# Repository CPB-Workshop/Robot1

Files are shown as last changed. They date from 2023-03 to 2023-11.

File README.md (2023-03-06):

# Robot1

## Code

Dans le dossier Code vous trouverez les différents codes pour tester les composants uns à uns de votre machine puis dans final en fonction du choix fait, une version "final" du code permettant de piloter completement la machine.

Tous les comportements "auto" n'ont pas été implémentés de sorte d'avoir un controle total de la machine, cependant les parechocs emettrons bien un signal et les photorésistances demandes normalement un étalonage pour chaques machines de sorte à ne pas envoyer un signal faux positif qui correspond a la lumière ambiante. Une routine est en cours de création pour automatiser cette dernière)

## Fritzing

Dans le dossier Fritzing vous trouverez le schéma de la machine en document Fritzing. le logiciel est distribué gratuitement et légalement sous une base de version précédente sur le site de l'éditeur ici : https://fritzing.org/releases/0-9-3b. Une version est ici jointe dans le zip pour exploiter le fichier et y découvrir le cablage de la machine.
ATTENTION le fichier CodeFull.ino (code arduino) n'est pas remplis, il correspond a ce que fritzing met a dispo avec le projet. Pour le bon code, voir la section précédente.

## WHAT'S NEXT

En cas de besoin/souhait d'évolution, n'hésitez pas à me contacter où à laisser une issue sur le projet.

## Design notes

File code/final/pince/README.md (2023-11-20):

# Code Final - Option Pince

Code final du mod "Pince" proposant de prendre le controlle complet de la machine via une application sur smartphone

## Flasher le robot

### 0. Installer le logiciel Arduino
Pour flasher le code, vous devrez installer arduino (https://downloads.arduino.cc/arduino-1.8.19-windows.exe)

### 1. Branchez l'arduino par USB
Vous devez débrancher le bluetooth (module bleu), prenez bien note de la manière dont tout est branché avant (prenez un photo, cela ne sera probablement pas de trop)

Si la pile est branché, débranchez la.

Branchez ensuite le cable USB sur le port de l'arduino et au PC, on est parré !

### 2. Récuperer le code

Une fois fait, téléchargez le code par ici (https://github.com/CPB-Workshop/Robot1/archive/refs/heads/main.zip)

Dezippez le et allez dans le dossier code / final / pince et double cliquez sur pince.ino

### 3. Réglage avant de flasher

Dans la section "outils", vous devez choisir :
* Type de carte : "Arduino Nano"
* Processeur: ou bien "ATMega328P" ou bien  "ATMega328P (Old bootloader)" cela dépend du microOS dans l'arduino, pas distinguible physiquement, a changer sur lors du flash cela ne marche pas
* Port: "ComX" X étant variable d'un pc a l'autre, d'un Port USB a l'autre. Normalement si vous avez branché avant d'ouvrir l'onglet vous devriez en voir au moins un. Si plus d'un, tentez de débrancher et rouvrir l'onglet pour voir lequel aurais disparus et qui serait donc votre Arduino

Cela donne en somme ceci a la fin (Old bootload ou port Com près)

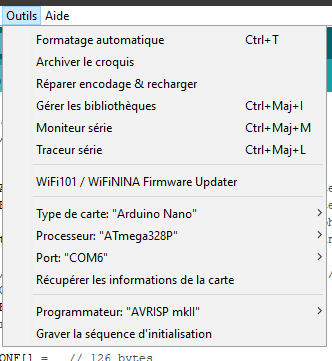
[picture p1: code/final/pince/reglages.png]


### 4. Flashez !

Utilisez la flèche pour verrifier le contenu du code, si aucune erreur n'apparait en rouge en dessous, utilisez la fleche pour transferrer le code

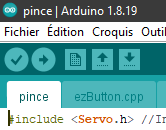
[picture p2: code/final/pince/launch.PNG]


### 5. Rebranchez...

Débranchez l'USB, rebranchez le bluetooth, rebranchez la batterie, on est partis !

### 6. L'app mobile

Pour le controller par bluetooth via votre smartphone android, il faut télécharger l'application RemoteXY

### AppStore
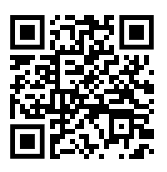
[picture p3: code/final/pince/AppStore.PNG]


### G-Play
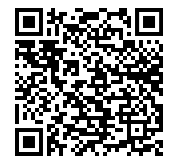
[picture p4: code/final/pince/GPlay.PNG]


et ajouter une nouvel appareil : le + en haut a droite 
puis bluetooth classic et vous devriez voir un appareil comme HC-05 ou HC-06 ou le nom que vous aurez choisis pour votre Robot.

Dès lors le robot est connecté et vous pouvez découvrir l'interface de controle pour expérimenter le code et vos modifs. Happy coding ;)

# TROUBLESHOOTING

## Robot qui avance pas droit ou recule
En cas de probleme de sens des moteurs (le robot tourne au lieux de rouler droit/recule) ont peut modifier le code a loisir sur la partie suivante :

```C++
    void lancerRotationMoteurPontA(bool marcheAvant, char vitesse) {
        digitalWrite(borneIN2, marcheAvant ? LOW : HIGH);    // inversion LOW et HIGH, Idem en dessous pour inverser le comportement d'une roue            
        digitalWrite(borneIN1, marcheAvant ? HIGH : LOW);
        
        analogWrite(borneENA, vitesse);       // Active l'alimentation du moteur 1
    }
    //[...]
    void lancerRotationMoteurPontB(bool marcheAvant, char vitesse) {
        digitalWrite(borneIN3, marcheAvant ? LOW : HIGH);    // inversion LOW et HIGH, Idem en dessous pour inverser le comportement d'une roue            
        digitalWrite(borneIN4, marcheAvant ? HIGH : LOW);
        
        analogWrite(borneENB, vitesse);       // Active l'alimentation du moteur 2
    }
```

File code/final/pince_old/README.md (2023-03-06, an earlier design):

# Code Final - Option Pince

Si vous avez décidé de passer par le code final, il faut alors flasher l'arduino (toujours bluetooth débranché) avec le code fournis (pince.ino)

Pour le controller par bluetooth via votre smartphone android, il faut télécharger l'application Bluetooth Electronics de Keuwlsoft

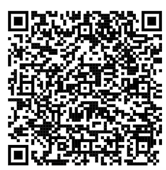
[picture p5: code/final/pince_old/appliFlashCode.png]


Ensuite importer le fichier "CPBRobotPince.kwl" pour obtenir un dashboard qui va permettre de commander la machine (ne pas oublier de rebrancher le bluetooth ;) )

# TROUBLESHOOTING

## Robot qui avant pas droit ou recule
En cas de probleme de sens des moteurs (le robot tourne au lieux de rouler droit/recule) ont peut modifier le code a loisir sur la partie suivante :

```C++
    void lancerRotationMoteurPontA(bool marcheAvant, char vitesse) {
        digitalWrite(borneIN2, marcheAvant ? LOW : HIGH);    // inversion LOW et HIGH, Idem en dessous pour inverser le comportement d'une roue            
        digitalWrite(borneIN1, marcheAvant ? HIGH : LOW);
        
        analogWrite(borneENA, vitesse);       // Active l'alimentation du moteur 1
    }
    //[...]
    void lancerRotationMoteurPontB(bool marcheAvant, char vitesse) {
        digitalWrite(borneIN3, marcheAvant ? LOW : HIGH);    // inversion LOW et HIGH, Idem en dessous pour inverser le comportement d'une roue            
        digitalWrite(borneIN4, marcheAvant ? HIGH : LOW);
        
        analogWrite(borneENB, vitesse);       // Active l'alimentation du moteur 2
    }
```

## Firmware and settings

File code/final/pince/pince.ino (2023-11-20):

#include <Servo.h> //Inclu avec arduino
#include "ezButton.h"
#include "RemoteXY/RemoteXY.h"

//REGLAGES
#define vitesseMinA 200 //à tester, a augmenter 1 par 1 si le moteur tourne pas a la même vitesse que l'autre quand ca doit aller droit (diff physique)
#define vitesseMinB 170 //à tester, a augmenter 1 par 1 si le moteur tourne pas a la même vitesse que l'autre quand ca doit aller droit (diff physique)
#define pinceFerme 0 //normalement est calibré au montage (diff physique) peux pas être négatif
#define pinceOuverte 140 //à tester, a augmenter 1 par 1 si la pince s'ouvre pas totalement (diff physique)

////////////////////////////////////////////////////////////////////////////////////////
//ACTIVATION CONTROLLE BLUETOOTH SUR LA SERIAL HARD (0-1)
#define REMOTEXY_SERIAL_SPEED 9600
//RemoteXY configurate  
#pragma pack(push, 1)
uint8_t RemoteXY_CONF[] =   // 126 bytes
  { 255,4,0,16,0,148,0,16,27,2,5,33,66,30,30,30,29,63,30,30,
  2,26,31,2,0,36,39,22,11,31,7,22,11,2,26,31,31,65,117,116,
  111,0,77,97,110,117,101,108,0,68,51,9,4,58,26,5,26,53,31,8,
  36,135,94,71,97,117,99,104,101,0,68,114,111,105,116,101,0,67,101,110,
  116,114,101,0,1,0,10,39,18,18,4,68,21,21,2,31,80,105,110,99,
  101,0,72,100,70,4,27,27,4,4,24,24,2,26,121,37,0,0,0,0,
  0,0,250,68,0,0,0,0,1,0,0,0,0,0,0,200,66,4,0,0,
  200,66,0,0,122,68,95,0,0,122,68,0,0,250,68 };
// this structure defines all the variables and events of your control interface 
struct {
  int8_t joystick_1_x; // from -100 to 100  
  int8_t joystick_1_y; // from -100 to 100  
  uint8_t switch_1; // =1 if switch ON and =0 if OFF 
  uint8_t button_1; // =1 if button pressed, else =0 
    // output variables
  float onlineGraph_1_var1;
  float onlineGraph_1_var2;
  float onlineGraph_1_var3;
  float circularbar_1;  // from 0 to 2000 
    // other variable
  uint8_t connect_flag;  // =1 if wire connected, else =0 
} RemoteXY;
#pragma pack(pop)
//////////////////////////////////////////////////////////////////////////////////////////

//CABLAGE MOTEUR
#define borneENA        6       // On associe la borne "ENA" du L298N à la pin D8 de l'arduino
#define borneIN1        7       // On associe la borne "IN1" du L298N à la pin D7 de l'arduino
#define borneIN2        8       // On associe la borne "IN2" du L298N à la pin D6 de l'arduino
#define borneIN3        5       // On associe la borne "IN3" du L298N à la pin D5 de l'arduino
#define borneIN4        4       // On associe la borne "IN4" du L298N à la pin D4 de l'arduino
#define borneENB        3       // On associe la borne "ENB" du L298N à la pin D3 de l'arduino

//CABLAGE SONAR
#define TRIGGER_PIN 11 // Broche TRIGGER
#define ECHO_PIN 12    // Broche ECHO

// SERVO
#define servoPin 10

// PARECHOC
#define SWITCHG 9 // Broche Gauche (a échanger en dessous si pas bon)
#define SWITCHD 2 // Broche Droite (a échanger au dessus si pas bon)

//PHOTORESISTANCES
#define RD A0  // composante photoresistor sur la pin A0
#define RC A1  // composante photoresistor sur la pin A1
#define RG A2  // composante photoresistor sur la pin A2

//CONSTANTES
/* Constantes pour le timeout */
const unsigned long MEASURE_TIMEOUT = 25000UL; // 25ms = ~8m à 340m/s
/* Vitesse du son dans l'air en mm/us */
const float SOUND_SPEED = 340.0 / 1000;

//STOCKAGE
String msg;
// Creation de l'objet servo
Servo myservo;
//Creation des objets parechoc
ezButton limitSwitchG(SWITCHG);  // create ezButton object;
ezButton limitSwitchD(SWITCHD);  // create ezButton object;
CRemoteXY *remotexy; //interface bluetooth

void setup() {
  
  // Configuration de toutes les pins de l'Arduino en "sortie" (car elles attaquent les entrées du module L298N)
  pinMode(borneENA, OUTPUT);
  pinMode(borneIN1, OUTPUT);
  pinMode(borneIN2, OUTPUT);
  pinMode(borneIN3, OUTPUT);
  pinMode(borneIN4, OUTPUT);
  pinMode(borneENB, OUTPUT);

  //SONAR
  pinMode(TRIGGER_PIN, OUTPUT);
  digitalWrite(TRIGGER_PIN, LOW); // La broche TRIGGER doit être à LOW au repos
  pinMode(ECHO_PIN, INPUT);

  //SERVO
  // appel de la fonction attach de l'objet
  myservo.attach(servoPin);
  //par defaut on ouvre
  myservo.write(pinceOuverte);

  //PARECHOC
  limitSwitchG.setDebounceTime(50); // set debounce time to 50 milliseconds
  limitSwitchD.setDebounceTime(50); // set debounce time to 50 milliseconds

  //PHOTORESISTANCES
  pinMode(RD, INPUT);
  pinMode(RC, INPUT);
  pinMode(RG, INPUT);


  //init bluetooth interface
  remotexy = new CRemoteXY (
    RemoteXY_CONF_PROGMEM, 
    &RemoteXY, 
    "", 
    new CRemoteXYStream_HardSerial (
      &Serial,       
      REMOTEXY_SERIAL_SPEED     // REMOTEXY_SERIAL_SPEED
    )
  ); 
}


void loop() {
  //d'abord on fait nos mesure
  float distanceMM = mesureSonar();
  RemoteXY.circularbar_1 = distanceMM;
  RemoteXY.onlineGraph_1_var1 = analogRead(RG);
  RemoteXY.onlineGraph_1_var2 = analogRead(RD);
  RemoteXY.onlineGraph_1_var3 = analogRead(RC);
  //readSerialPort();
  checkParechoc(RemoteXY.switch_1);
  //TODO lux sensor
  //ensuite on rafraichis l'interface
  remotexy->handler();
  //et enfin on écris sur nos moteurs et pince ce qu'on a recus comme ordre
  autoPince(RemoteXY.switch_1, RemoteXY.button_1, distanceMM);

  
  lancerRotationMoteurPontA(map(RemoteXY.joystick_1_y-RemoteXY.joystick_1_x,-150,150,-(vitesseMinA*1.5),(vitesseMinA*1.5))); //1.5 car 150 max (75+75 -> digonal) donc le max doit être de 150%
  lancerRotationMoteurPontB(map(RemoteXY.joystick_1_y+RemoteXY.joystick_1_x,-150,150,-(vitesseMinB*1.5),(vitesseMinB*1.5)));
  ///////////////////////////////////////
  //       100
  //
  //-100    *    100
  //
  //      -100
  //////////////////////////////////////
}

void tournerGauche(){
  lancerRotationMoteurPontA(-vitesseMinA);
  lancerRotationMoteurPontB(vitesseMinB);
}

void tournerDroite(){
  lancerRotationMoteurPontA(vitesseMinA);
  lancerRotationMoteurPontB(-vitesseMinB);
}

float mesureSonar(){
 /* 1. Lance une mesure de distance en envoyant une impulsion HIGH de 10µs sur la broche TRIGGER */
  digitalWrite(TRIGGER_PIN, HIGH);
  delayMicroseconds(10);
  digitalWrite(TRIGGER_PIN, LOW);
  
  /* 2. Mesure le temps entre l'envoi de l'impulsion ultrasonique et son écho (si il existe) */
  long measure = pulseIn(ECHO_PIN, HIGH, MEASURE_TIMEOUT);
   
  /* 3. Calcul et renvois de la distance en mm à partir du temps mesuré */
  return (measure / 2.0 * SOUND_SPEED);
}

void lancerRotationMoteurPontA(long vitesse) {
  bool marcheAvant = vitesse > -0.1 ? true : false;
  digitalWrite(borneIN2, marcheAvant ? HIGH : LOW);                
  digitalWrite(borneIN1, marcheAvant ? LOW : HIGH);
  analogWrite(borneENA, vitesse);       // Active l'alimentation du moteur 1
}

void arreterRotationMoteurPontA(){
  analogWrite(borneENA, 0);        // Désactive l'alimentation du moteur 1
}

void lancerRotationMoteurPontB(long vitesse) {
  bool marcheAvant = vitesse > -0.1 ? true : false;
  digitalWrite(borneIN3, marcheAvant ? HIGH : LOW);                
  digitalWrite(borneIN4, marcheAvant ? LOW : HIGH);
  analogWrite(borneENB, vitesse);       // Active l'alimentation du moteur 2
}

void arreterRotationMoteurPontB(){
  analogWrite(borneENB, 0);        // Désactive l'alimentation du moteur 2
}

void actionPince(int angle){
   myservo.write(angle);
}

////////////////////////////////////////AUTOMATIC MODE

/**
 * Fonction pour piloter la pince, prend en compte un flag du mode auto et ferme la pince automatiquement. pour la rouvrir, presser le bouton
 */
void autoPince(bool autoMode, bool buttonManual, float sonarDistanceObjct){
  if(autoMode){//Si le mode auto ALORS
    if(buttonManual){ //SI je presse le button 
       actionPince(pinceOuverte);//on ouvre
    } else if (sonarDistanceObjct <= 30 ) { // SINON Si l'objet est a moins ou égale à 30mm (3cm) ALORS
      actionPince(pinceFerme);
    }
  }else{//SINON (Si pas mode Auto ALORS
    if(buttonManual){//SI le bouton est pressé ALORS
      actionPince(pinceFerme); // pince fermé
    }else{ // Sinon
      actionPince(pinceOuverte); // pince ouverte
    }
  }
}
/**
 * Routine auto des parechoc. Doit être désctivé en mode auto (la pince en mode auto gene
 */
void checkParechoc(bool autoMode){
  limitSwitchG.loop(); // MUST call the loop() function first
  limitSwitchD.loop(); // MUST call the loop() function first
  if(!autoMode && (limitSwitchG.getState() == LOW || limitSwitchD.getState() == LOW)){ // SI(INVERSE du mode auto (donc le manuel) ET (Switch gauche pressé OU Switch droit pressé)) ALORS ->
    lancerRotationMoteurPontB(-vitesseMinB); //roule en arriere pour le moteur A
    lancerRotationMoteurPontA(-vitesseMinA); //roule en arriere pour le moteur B
    delay(1000);//pendant 1 sec
    arreterRotationMoteurPontA(); //on arrete A
    arreterRotationMoteurPontB(); //on arrete B
  }
}

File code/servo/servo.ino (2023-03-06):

#include <Servo.h>

// Creation de l'objet servo
Servo myservo;

// Definition du port du servo
#define servoPin 10

// Variable globale pour stocker la position
int angle = 0;

void setup() {
  // appel de la fonction attach de l'objet
  myservo.attach(servoPin);
}

void loop() {
  // Aller a un angle précis
  myservo.write(90);
  delay(1000);
  
  myservo.write(140);
  delay(1000);
  
  myservo.write(0);
  delay(1000);
  
  // balayage de 0 a 180 degrees
  for (angle = 0; angle <= 140; angle += 1) {
    myservo.write(angle);
    delay(15);
  }
  
  // Balayage inverse (de 180 à 0)
  for (angle = 140; angle >= 0; angle -= 1) {
    myservo.write(angle);
    delay(30);
  }
  
  delay(1000);
}
